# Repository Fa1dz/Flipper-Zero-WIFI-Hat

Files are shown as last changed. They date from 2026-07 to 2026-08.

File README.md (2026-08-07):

# Flipper-Zero-WIFI-Hat
Designing a wifi hat for the flipper zero from scratch using the ESP-32 and a custom PCB. The device was designed in KiCad.

# Bill of Materials (BOM)

This BOM contains all components required for the build, including electronics, PCB fabrication, shipping estimates, and the Flipper Zero used for development/testing.

Prices are based on the supplied supplier quotes.

---

# Electronic Components

| Qty | Manufacturer | Part Number | Description | Unit Price (NOK) | Total (NOK) | Link |
| --: | --- | --- | --- | ---: | ---: | ---- |
| 2 | Kamaya | RMC1/10K5101DTP | Thick Film Resistors - SMD 0805, 5.10 kΩ, 0.5%, Lead Free | 1.82 | 3.64 | https://no.mouser.com/en/ProductDetail/Kamaya/RMC1-10K5101DTP?qs=GedFDFLaBXG1LvR8QK0EcA%3D%3D |
| 10 | Bourns | CR2512AJW-103ELF | Thick Film Resistors - SMD 2512, 10 kΩ, 5%, 1 W | 1.08 | 10.80 | https://no.mouser.com/en/ProductDetail/Bourns/CR2512AJW-103ELF?qs=GedFDFLaBXEqggePGBQmuQ%3D%3D |
| 1 | Same Sky | UJ20-C-H-G-MSMT-4B-P16-TR | USB Connector, Type-C 2.0, Horizontal SMT, 16 Pin | 4.51 | 4.51 | https://no.mouser.com/en/ProductDetail/Same-Sky/UJ20-C-H-G-MSMT-4B-P16-TR?qs=6avfeC6zeS47Lo0obtd7QQ%3D%3D |
| 2 | Same Sky | TS04-66-65-BK-260-SMT | Tactile Switch, 6 × 6 mm, 6.5 mm Actuator, 260 gf | 1.73 | 3.46 | https://no.mouser.com/en/ProductDetail/Same-Sky/TS04-66-65-BK-260-SMT?qs=A6eO%252BMLsxmTvOTHTIBabhQ%3D%3D |
| 5 | Murata | GRM155D70G106ME18D | MLCC SMD 0402, 10 µF, 4 V, X7T, ±20% | 3.94 | 19.70 | https://no.mouser.com/en/ProductDetail/Murata/GRM155D70G106ME18D?qs=doiCPypUmgEf2sthzNH4lA%3D%3D |
| 1 | Microchip | MCP1827S-3302E/EBVAO | LDO Voltage Regulator, 3.3 V, 1.5 A | 17.74 | 17.74 | https://no.mouser.com/en/ProductDetail/Microchip/MCP1827S-3302E-EBVAO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 |
| 1 | onsemi | 2N7002WT1G | Small Signal N-Channel MOSFET | 1.92 | 1.92 | https://no.mouser.com/en/ProductDetail/onsemi/2N7002WT1G?qs=Jh7l0IbPjidRgzyVQt6Xnw%3D%3D |
| 1 | Same Sky | CPT-1775-3TH | Board Mount Buzzer, 3 V, 75 dB, Through Hole | 10.85 | 10.85 | https://no.mouser.com/en/ProductDetail/Same-Sky/CPT-1775-3TH?qs=yc9RBI4tIAK9HFcgM%252BStOQ%3D%3D |
| 1 | Espressif | ESP32-S3-WROOM-1-N16R8 | ESP32-S3 Module, 16 MB Flash, 8 MB PSRAM, PCB Antenna | 64.73 | 64.73 | https://no.mouser.com/en/ProductDetail/Espressif/ESP32-S3-WROOM-1-N16R8?qs=Li%252BoUPsLEnvQc9gW6AMhZg%3D%3D |
| 1 | Espressif | ESP32-S3-WROOM-1U-N8 | ESP32-S3 Module, 8 MB Flash, IPEX Antenna Connector | 54.35 | 54.35 | https://no.mouser.com/en/ProductDetail/Espressif/ESP32-S3-WROOM-1U-N8?qs=Li%252BoUPsLEntthfxdhgRI1w%3D%3D |
| 1 | Taoglas | GW17.07.0250E | IPEX Terminal Antenna | 80.13 | 80.13 | https://no.mouser.com/en/ProductDetail/Taoglas/GW17.07.0250E?qs=AL7xPqYNrmTPXhCuHzQycg%3D%3D |
| 1 | Würth Elektronik | 693072010801 | MicroSD Card Connector, 8 Pin Hinge | 32.70 | 32.70 | https://no.mouser.com/en/ProductDetail/Wurth-Elektronik/693072010801?qs=7gQLVZk5cPmw4uU1mAcUFg%3D%3D |

## Electronics Subtotal

**303.53 NOK (~$31.57 USD)**

---

# PCB Manufacturing

| Qty | Item | Cost (NOK) | Link |
| --: | ---- | ---: | ---- |
| 1 | PCB + SMT stencil including shipping | 250.00 | JLCPCB |

## PCB Subtotal

**250.00 NOK (~$26 USD)**

---

# Additional Hardware

| Qty | Item | Cost (NOK) | Link |
| --: | ---- | ---: | ---- |
| 1 | Flipper Zero | 2656.00 | https://www.joom.com/en/products/62f661838ed09b01ebd4e0e2 |

## Hardware Subtotal

**2656.00 NOK (~$276.22 USD)**

---

# Shipping

| Item | Cost (NOK) |
| ---- | ---: |
| Mouser shipping and tax estimate | 459.61 |

## Shipping Subtotal

**459.61 NOK (~$47.80 USD)**

---

# Final Cost Summary

| Category | NOK | USD Approx. |
| --- | --: | ---: |
| Electronic components | 303.53 | $31.57 |
| PCB + SMT stencil including shipping | 250.00 | $26.00 |
| Mouser shipping/tax | 459.61 | $47.80 |
| Flipper Zero | 2656.00 | $276.22 |

---

# Total Project Cost

## Complete Build

**3669.14 NOK**

**≈ $381 USD**

Budget estimate: **~$400 USD**

---

# Notes

- The BOM includes both ESP32-S3-WROOM modules:
  - ESP32-S3-WROOM-1-N16R8 (PCB antenna)
  - ESP32-S3-WROOM-1U-N8 (IPEX antenna connector)

- The Taoglas GW17.07.0250E antenna is required for the WROOM-1U module.

- Solder paste and hot plate equipment have been removed from the BOM.

- AliExpress items and shipping estimates have been removed.

- PCB cost updated to include PCB + SMT stencil + shipping.

- Prices are based on supplied order data and may change with exchange rates.

# Notes

- The BOM includes both ESP32-S3-WROOM modules:
  - ESP32-S3-WROOM-1-N16R8 (PCB antenna)
  - ESP32-S3-WROOM-1U-N8 (IPEX antenna connector)

- The Taoglas GW17.07.0250E antenna is required for the WROOM-1U module.

- Solder paste and hot plate equipment have been removed from the BOM.

- AliExpress items and shipping estimates have been removed.

- Prices are based on supplied quotes and may change with exchange rates.

# Notes

- The BOM includes both ESP32-S3-WROOM modules from the original order:
  - ESP32-S3-WROOM-1-N16R8 (PCB antenna)
  - ESP32-S3-WROOM-1U-N8 (IPEX antenna connector)
- The Taoglas GW17.07.0250E antenna is required for the WROOM-1U module.
- Solder paste and hot plate equipment have been removed from the BOM.
- AliExpress shipping estimate has been removed.
- Prices are based on the supplied order data and may change with exchange rates.

## Notes

- ESP32-S3-WROOM-1-N16R8 and ESP32-S3-WROOM-1U-N8 are both included from the original order list.
- The Taoglas GW17.07.0250E antenna is used with the ESP32-S3-WROOM-1U-N8 module.
- Assembly tools and solder paste have been removed from this BOM.
- Prices are based on the supplied quotes and may change with exchange rates and supplier pricing.
## Notes

- The BOM includes both ESP32-S3-WROOM variants as listed in the order:
  - ESP32-S3-WROOM-1-N16R8 (PCB antenna)
  - ESP32-S3-WROOM-1U-N8 (IPEX antenna)
- The Taoglas GW17.07.0250E antenna is required for the WROOM-1U module.
- Prices are based on the supplied Mouser/JLCPCB/AliExpress/Joom estimates.
- USD conversions are approximate and will vary with exchange rates.

*Approx 255 dollars to be safe*

Features:
USB-C for flashing the ESP-32-S3-WROOM-1 module
ISTP port for antennas
Bluetooth Low Energy compatibiltiy
WIFI 2.4ghz compatability
Fully designed for Flipper Zero pins
Is compatible with Flipper Zero wifi marauder
MicroSD compatible for storage of large data packets to prevent cluttering of the UART communication

Here are some pictures of the design:




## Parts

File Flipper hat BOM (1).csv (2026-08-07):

Store No | Mfr. No | Description | Order Qty. | Price (NOK) | Ext.: (NOK) | link
791-RMC1/10K5101DTP | RMC1/10K5101DTP | Thick Film Resistors - SMD 0805 5K10 0.5% Lead Free | 2 | kr 1,82 | 3.64 | https://no.mouser.com/en/ProductDetail/Kamaya/RMC1-10K5101DTP?qs=GedFDFLaBXG1LvR8QK0EcA%3D%3D
652-CR2512AJW-103ELF | CR2512AJW-103ELF | Thick Film Resistors - SMD ResA 2512 10k 5% 1W TC200 | 10 | kr 1,08 | 10.8 | https://no.mouser.com/en/ProductDetail/Bourns/CR2512AJW-103ELF?qs=GedFDFLaBXEqggePGBQmuQ%3D%3D
179-CHGMSMT4BP16TR | UJ20-C-H-G-MSMT-4B-P16-TR | USB Connectors USB Jack, Type C, 2.0, MSMT, Horizontal, Gold Flash, 16 Pin, TR | 1 | kr 4,51 | 4.51 | https://no.mouser.com/en/ProductDetail/Same-Sky/UJ20-C-H-G-MSMT-4B-P16-TR?qs=6avfeC6zeS47Lo0obtd7QQ%3D%3D
179-TS046665BK260SMT | TS04-66-65-BK-260-SMT | Tactile Switches 6 x 6 mm, 6.5 mm Act Height, 260 gf, Black, Surface Mount, SPST, | 2 | kr 1,73 | 3.46 | https://no.mouser.com/en/ProductDetail/Same-Sky/TS04-66-65-BK-260-SMT?qs=A6eO%252BMLsxmTvOTHTIBabhQ%3D%3D
81-GRM155D70G106ME8D | GRM155D70G106ME18D | Multilayer Ceramic Capacitors MLCC - SMD/SMT 0402 4VDC 10uF 20% X7T | 5 | kr 3,94 | 19.7 | https://no.mouser.com/en/ProductDetail/Murata/GRM155D70G106ME18D?qs=doiCPypUmgEf2sthzNH4lA%3D%3D
579-M827S302EEBVAO | MCP1827S-3302E/EBVAO | LDO Voltage Regulators 1.5A LDO Regulator | 1 | kr 17,74 | 17.74 | https://no.mouser.com/en/ProductDetail/Microchip/MCP1827S-3302E-EBVAO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
863-2N7002WT1G | 2N7002WT1G | MOSFETs SMALL SIGNAL MOSFET 6.8V LO C | 1 | kr 1,92 | 1.92 | https://no.mouser.com/en/ProductDetail/onsemi/2N7002WT1G?qs=Jh7l0IbPjidRgzyVQt6Xnw%3D%3D
179-CPT-1775-3TH | CPT-1775-3TH | Buzzers & Audio Indicators - Board Mount buzzer, 17 mm x 7.5 mm deep, P, 3 V, 75 dB, Through Hole, Audio Transducer | 1 | kr 10,85 | 10.85 | https://no.mouser.com/en/ProductDetail/Same-Sky/CPT-1775-3TH?qs=yc9RBI4tIAK9HFcgM%252BStOQ%3D%3D
356-ESP32S3WRM1N16R8 | ESP32-S3-WROOM-1-N16R8 | Multiprotocol Modules SMD module, ESP32-S3R8 with 3.3V, 8 MB Octal PSRAM die inside, 16 MB Quad SPI flash, PCB antenna | 1 | kr 64,73 | 64.73 | https://no.mouser.com/en/ProductDetail/Espressif/ESP32-S3-WROOM-1-N16R8?qs=Li%252BoUPsLEnvQc9gW6AMhZg%3D%3D
356-ESP32S3WROOM1UN8 | ESP32-S3-WROOM-1U-N8 | Multiprotocol Modules SMD module, ESP32-S3, 8 MB SPI flash, IPEX antenna connector | 1 | kr 54,35 | 54.35 | https://no.mouser.com/en/ProductDetail/Espressif/ESP32-S3-WROOM-1U-N8?qs=Li%252BoUPsLEntthfxdhgRI1w%3D%3D
960-GW.17.07.0250E | GW17.07.0250E | Antennas IPEX TERMINAL ANTENNA | 1 | kr 80,13 | 80.13 | https://no.mouser.com/en/ProductDetail/Taoglas/GW17.07.0250E?qs=AL7xPqYNrmTPXhCuHzQycg%3D%3D
710-693072010801 | 693072010801 | Memory Card Connectors WR-CRD SD Micro Card 8Pin Hinge | 1 | kr 32,70 | 32.7 | https://no.mouser.com/en/ProductDetail/Wurth-Elektronik/693072010801?qs=7gQLVZk5cPmw4uU1mAcUFg%3D%3D
--- | --- | PCB including shipping | 1 | kr 400 | 400.00 | JLCPCB Shopping Cart | Secure Checkout for Your Orders
--- | --- | shipping estimate and tax Mouser | --- | --- | 459.61
--- | --- | flipper zero | 1 | kr 2656 | 2656 | Flipper Zero | https://www.joom.com/en/products/62f661838ed09b01ebd4e0e2?variant_id=62f661838ed09b43ebd4e0e4

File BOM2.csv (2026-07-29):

FLIPPER_HAT
Mouser No | Mfr. No | Manufacturer | Customer No | Description | RoHS | Lifecycle | Order Qty. | Price (EUR) | Ext.: (EUR) | Country of Origin | Assembly Country of Origin | Country of Diffusion
791-RMC1/10K5101DTP | RMC1/10K5101DTP | Kamaya |  | Thick Film Resistors - SMD 0805 5K10 0.5% Lead Free | RoHS Compliant By Exemption |  | 2 | 0,163 ? | 0,33 ? | Malaysia
652-CR2512AJW-103ELF | CR2512AJW-103ELF | Bourns |  | Thick Film Resistors - SMD ResA 2512 10k 5% 1W TC200 | RoHS Compliant By Exemption |  | 9 | 0,232 ? | 2,09 ? | Taiwan
179-CHGMSMT4BP16TR | UJ20-C-H-G-MSMT-4B-P16-TR | Same Sky |  | USB Connectors USB Jack, Type C, 2.0, MSMT, Horizontal, Gold Flash, 16 Pin, TR | RoHS Compliant | New Product | 1 | 0,404 ? | 0,40 ? | China
179-TS046665BK260SMT | TS04-66-65-BK-260-SMT | Same Sky |  | Tactile Switches 6 x 6 mm, 6.5 mm Act Height, 260 gf, Black, Surface Mount, SPST, | RoHS Compliant |  | 2 | 0,163 ? | 0,33 ? | China
81-GRM155D70G106ME8D | GRM155D70G106ME18D | Murata |  | Multilayer Ceramic Capacitors MLCC - SMD/SMT 0402 4VDC 10uF 20% X7T | RoHS Compliant | New Product | 5 | 0,353 ? | 1,77 ? | Japan
579-M827S302EEBVAO | MCP1827S-3302E/EBVAO | Microchip |  | LDO Voltage Regulators 1.5A LDO Regulator | RoHS Compliant | New Product | 1 | 1,59 ? | 1,59 ? | China
863-2N7002WT1G | 2N7002WT1G | onsemi |  | MOSFETs SMALL SIGNAL MOSFET 6.8V LO C | RoHS Compliant |  | 1 | 0,172 ? | 0,17 ? | China | China | Taiwan
179-CPT-1775-3TH | CPT-1775-3TH | Same Sky |  | Buzzers & Audio Indicators - Board Mount buzzer, 17 mm x 7.5 mm deep, P, 3 V, 75 dB, Through Hole, Audio Transducer | RoHS Compliant | New Product | 1 | 0,972 ? | 0,97 ? | China
356-ESP32S3WRM1N16R8 | ESP32-S3-WROOM-1-N16R8 | Espressif |  | Multiprotocol Modules SMD module, ESP32-S3R8 with 3.3V, 8 MB Octal PSRAM die inside, 16 MB Quad SPI flash, PCB antenna | RoHS Compliant |  | 1 | 5,80 ? | 5,80 ? | China
356-ESP32S3WROOM1UN8 | ESP32-S3-WROOM-1U-N8 | Espressif |  | Multiprotocol Modules SMD module, ESP32-S3, 8 MB SPI flash, IPEX antenna connector | RoHS Compliant |  | 1 | 4,87 ? | 4,87 ? | China
960-GW.17.07.0250E | GW17.07.0250E | Taoglas |  | Antennas IPEX TERMINAL ANTENNA | RoHS Compliant |  | 1 | 11,53 ? | 11,53 ? | Taiwan
485-5903 | 5903 | Adafruit |  | Soldering & Desoldering Stations Mini Brass Hot Plate Preheater with USB-C PD or DC - MHP50-B5 | RoHS Compliant |  | 1 | 111,75 ? | 111,75 ? | China
910-RMA591AX10 | RMA591AX10 | Chip Quik |  | Solder RMA Solder Paste SN63/PB37 T4 (35g Syringe) | No | New At Mouser | 1 | 14,60 ? | 14,60 ? | Canada

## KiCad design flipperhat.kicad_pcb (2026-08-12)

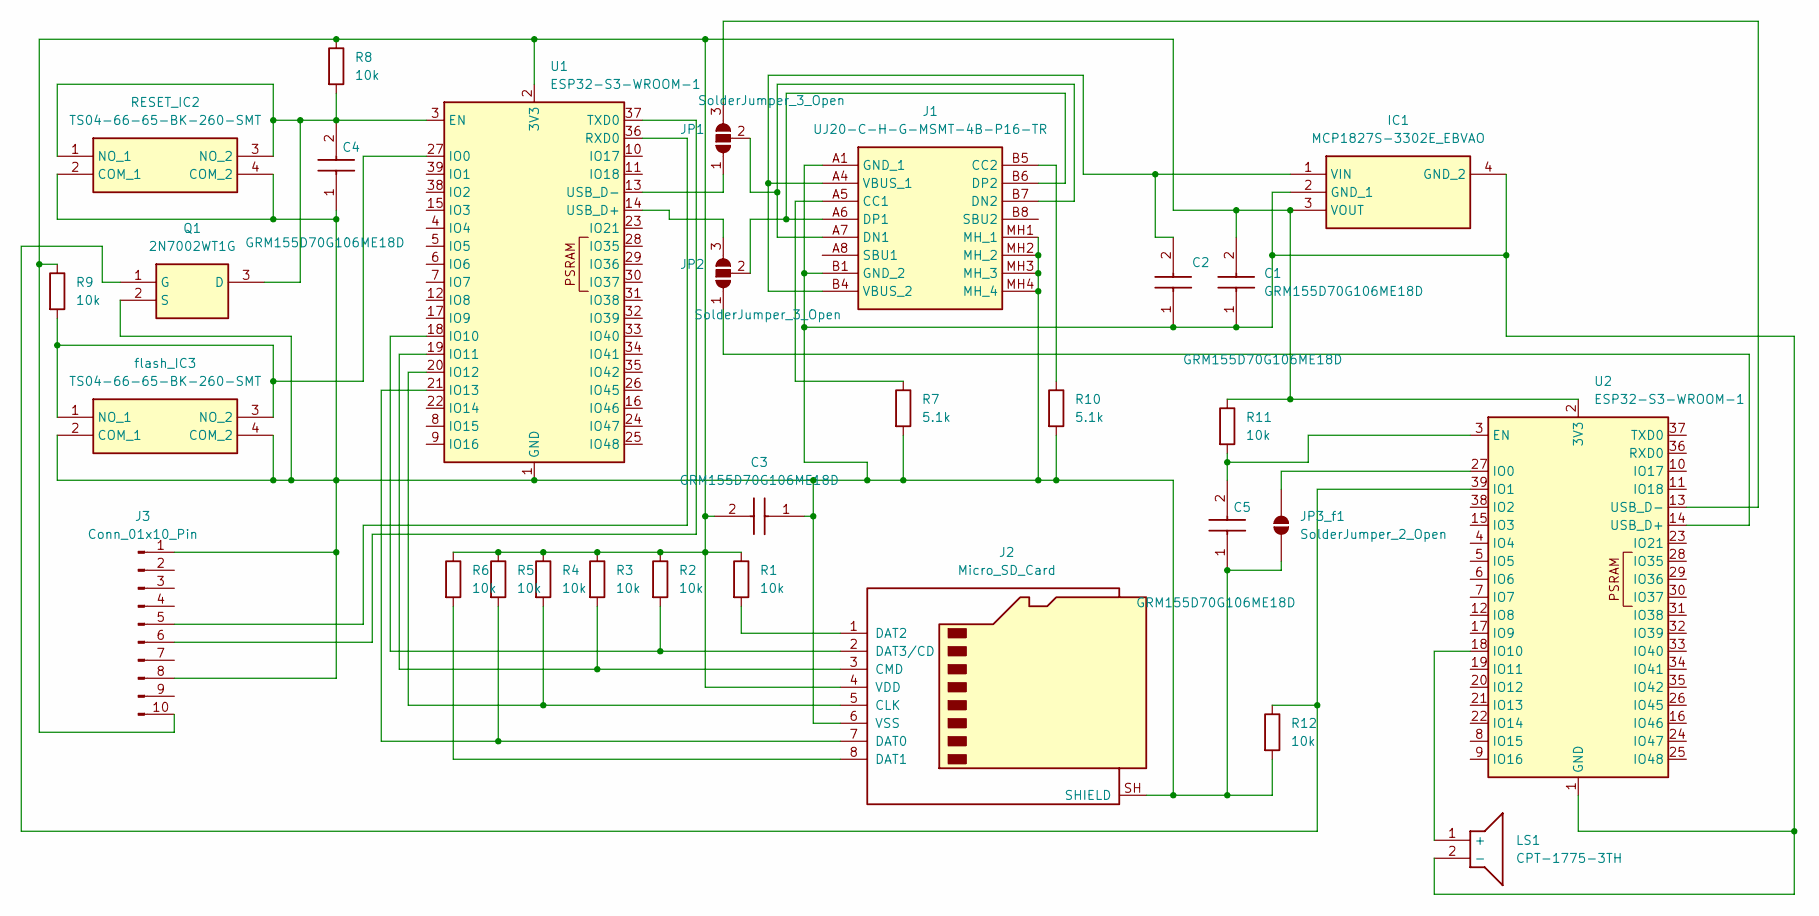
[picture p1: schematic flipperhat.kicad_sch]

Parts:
C1, C2, C3, C4, C5: GRM155D70G106ME18D; CAPC1005X70N; Manufacturer_Part_Number GRM155D70G106ME18D
IC1: MCP1827S-3302E_EBVAO; MCP1827S3302EEBVAO; Manufacturer_Part_Number MCP1827S-3302E/EBVAO
J1: UJ20-C-H-G-MSMT-4B-P16-TR; UJ20CHGMSMT4BP16TR; Manufacturer_Part_Number UJ20-C-H-G-MSMT-4B-P16-TR
J2: Micro_SD_Card; microSD_HC_Wuerth_693072010801
J3: Conn_01x10_Pin; PinHeader_1x10_P2.54mm_Vertical
JP1, JP2: SolderJumper_3_Open; SolderJumper-3_P1.3mm_Open_RoundedPad1.0x1.5mm
JP3_f1: SolderJumper_2_Open; SolderJumper-2_P1.3mm_Open_RoundedPad1.0x1.5mm
LS1: CPT-1775-3TH; CPT17753TH; Manufacturer_Part_Number CPT-1775-3TH
Q1: 2N7002WT1G; SOT65P220X100-3N; Mouser Part Number 863-2N7002WT1G
R1, R2, R3, R4, R5, R6, R8, R9, R11, R12: 10k; R_2512_6332Metric_Pad1.40x3.35mm_HandSolder
R7, R10: 5.1k; R_0805_2012Metric_Pad1.20x1.40mm_HandSolder
RESET_IC2: TS04-66-65-BK-260-SMT; TS046665BK260SMT; Mouser Part Number 179-TS046665BK260SMT
U1, U2: ESP32-S3-WROOM-1
flash_IC3: TS04-66-65-BK-260-SMT; TS046665BK260SMT; Mouser Part Number 179-TS046665BK260SMT

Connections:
unnamed: C1.1, C2.1, C3.1, C4.1, C5.1, IC1.2 (GND_1), IC1.4 (GND_2), J1.A1 (GND_1), J1.B1 (GND_2), J1.MH1 (MH_1), J1.MH2 (MH_2), J1.MH3 (MH_3), J1.MH4 (MH_4), J2.6 (VSS), J2.SH (SHIELD), J3.1, J3.8, JP3_f1.1 (A), LS1.2 (-), Q1.2 (S), R7.2, R10.2, R12.2, RESET_IC2.2 (COM_1), RESET_IC2.4 (COM_2), U1.1 (GND), U1.40 (GND), U1.41 (GND), U2.1 (GND), U2.40 (GND), U2.41 (GND), flash_IC3.2 (COM_1), flash_IC3.4 (COM_2)
unnamed: C2.2, IC1.1 (VIN), J1.A4 (VBUS_1), J1.B4 (VBUS_2)
unnamed: C1.2, C3.2, IC1.3 (VOUT), J2.4 (VDD), J3.10, R1.1, R2.1, R3.1, R4.1, R5.1, R6.1, R8.1, R9.1, R11.1, U1.2 (3V3), U2.2 (3V3)
unnamed: J1.A5 (CC1), R7.1
unnamed: J1.B5 (CC2), R10.1
unnamed: J1.A7 (DN1), J1.B7 (DN2), JP1.2 (C)
unnamed: J1.A6 (DP1), J1.B6 (DP2), JP2.2 (C)
unnamed: J2.5 (CLK), R4.2, U1.20 (IO12)
unnamed: J2.3 (CMD), R3.2, U1.19 (IO11)
unnamed: J2.7 (DAT0), R5.2, U1.21 (IO13)
unnamed: J2.8 (DAT1), R6.2
unnamed: J2.1 (DAT2), R1.2
unnamed: J2.2 (DAT3/CD), R2.2, U1.18 (IO10)
unnamed: J3.5, U1.36 (RXD0)
unnamed: J3.6, U1.37 (TXD0)
unnamed: JP1.1 (A), U1.13 (USB_D-)
unnamed: JP1.3 (B), U2.13 (USB_D-)
unnamed: JP2.1 (A), U2.14 (USB_D+)
unnamed: JP2.3 (B), U1.14 (USB_D+)
unnamed: JP3_f1.2 (B), U2.27 (IO0)
unnamed: LS1.1 (+), U2.18 (IO10)
unnamed: C4.2, Q1.3 (D), R8.2, RESET_IC2.1 (NO_1), RESET_IC2.3 (NO_2), U1.3 (EN)
unnamed: Q1.1 (G), R12.1, U2.39 (IO1)
unnamed: R9.2, U1.27 (IO0), flash_IC3.1 (NO_1), flash_IC3.3 (NO_2)
unnamed: C5.2, R11.2, U2.3 (EN)

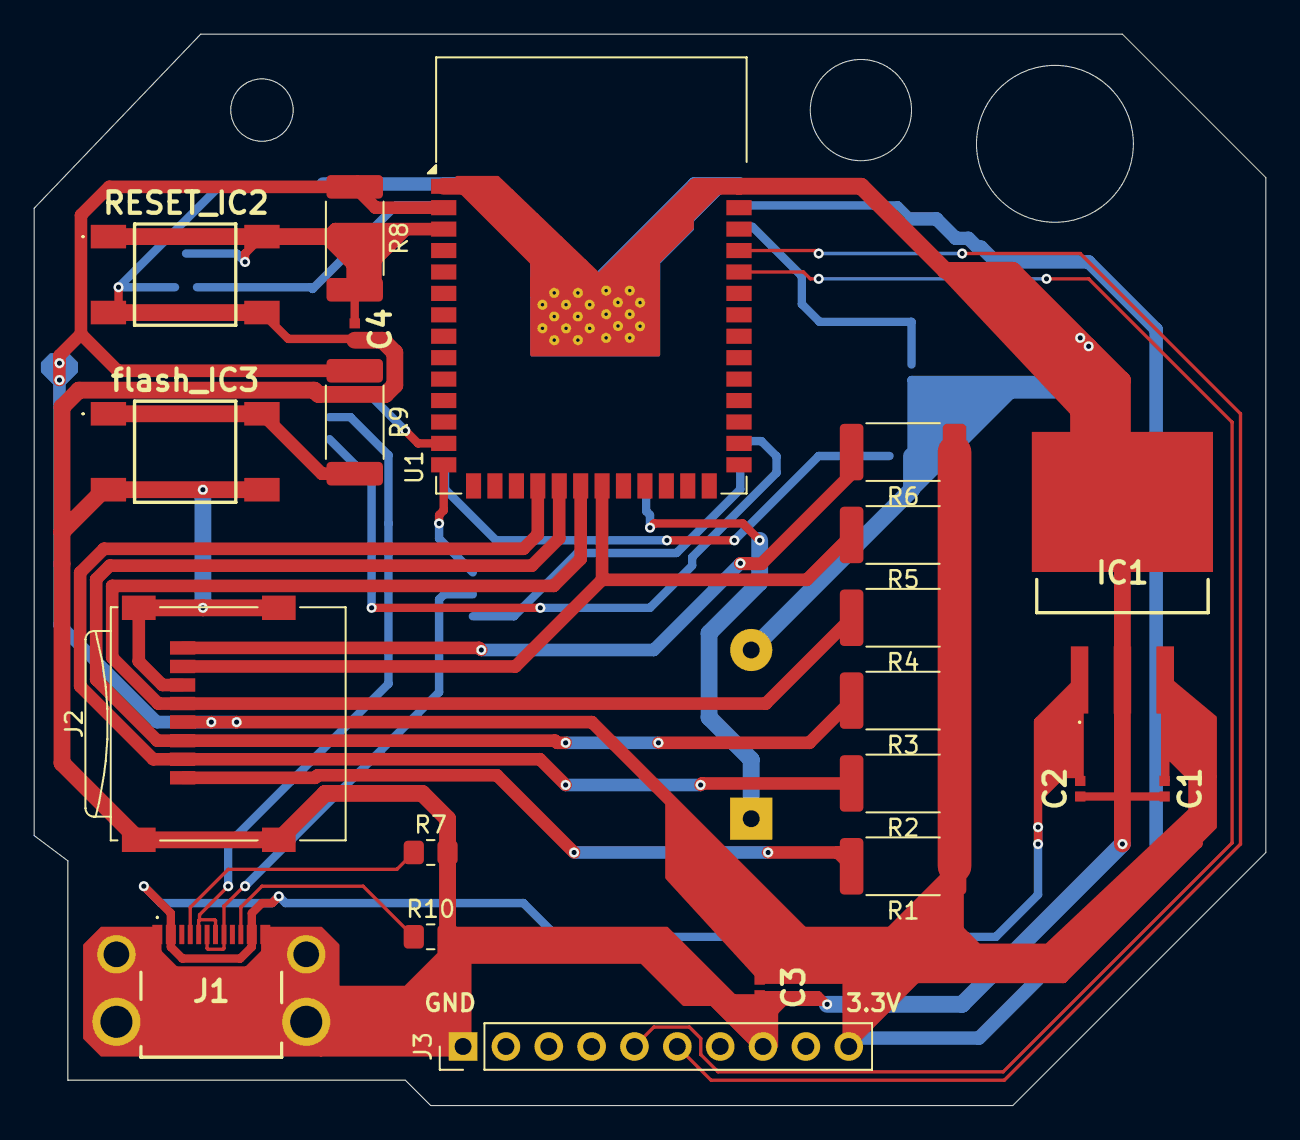
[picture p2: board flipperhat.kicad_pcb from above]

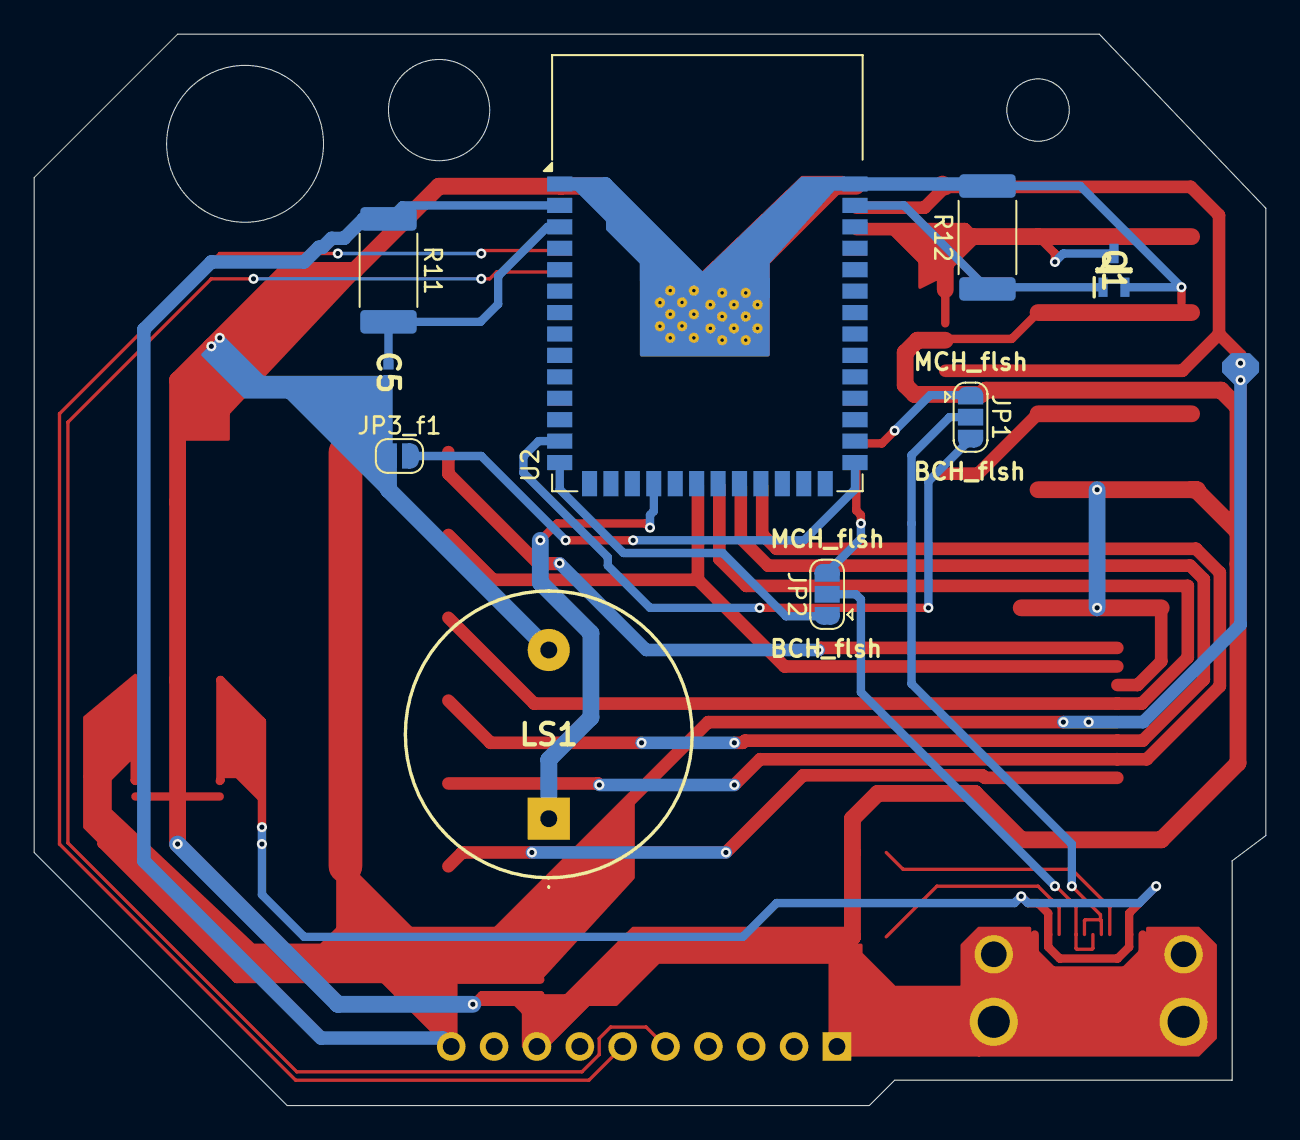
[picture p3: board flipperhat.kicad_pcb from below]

Board: 2 copper layers, 73.0 x 63.5 mm, 30 parts (9 on the bottom side), 25 nets.

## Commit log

2026-08-07 Add BOM section to README
    Added Bill of Materials (BOM) with component details and links.
2026-08-07 Revise BOM format and add cost estimates
    Updated the Bill of Materials (BOM) section with a structured table format and added additional costs and estimated total.
2026-08-07 Convert BOM and costs from kr to USD
    Updated the Bill of Materials and cost estimates to reflect USD pricing instead of kr.
2026-08-07 Revise BOM and add cost summary for project
    Updated the Bill of Materials (BOM) section with additional costs, assembly materials, and a cost summary for the project.
2026-08-07 Revise BOM with detailed descriptions and costs
    Updated the Bill of Materials (BOM) with detailed descriptions and corrected item names. Adjusted total costs and added shipping estimates.
2026-08-07 Revise BOM pricing and update project cost summary
    Updated the README with revised pricing and subtotals for components, PCB, hardware, shipping, and total project cost. Added notes regarding changes in the BOM and removed specific shipping estimates.
2026-08-07 Modify Flipper hat BOM with new entries and estimates
    Updated the Flipper hat BOM with additional components and shipping estimates.
    [Flipper hat BOM (1).csv]
2026-08-07 Revise BOM with updated part numbers and costs
    Updated part numbers, costs, and links in the BOM. Adjusted subtotals and final project cost estimates.
2026-08-07 Fix table formatting and item details in README
    Updated table formatting and corrected item descriptions in the BOM.
2026-08-07 Revise component links and update section headers
    Updated links for electronic components and adjusted section headers for better clarity. Added additional details for PCB and hardware subtotals.
2026-08-12 Flipperhat PCB SOURCE FILE
    [flipperhat.kicad_pcb]
